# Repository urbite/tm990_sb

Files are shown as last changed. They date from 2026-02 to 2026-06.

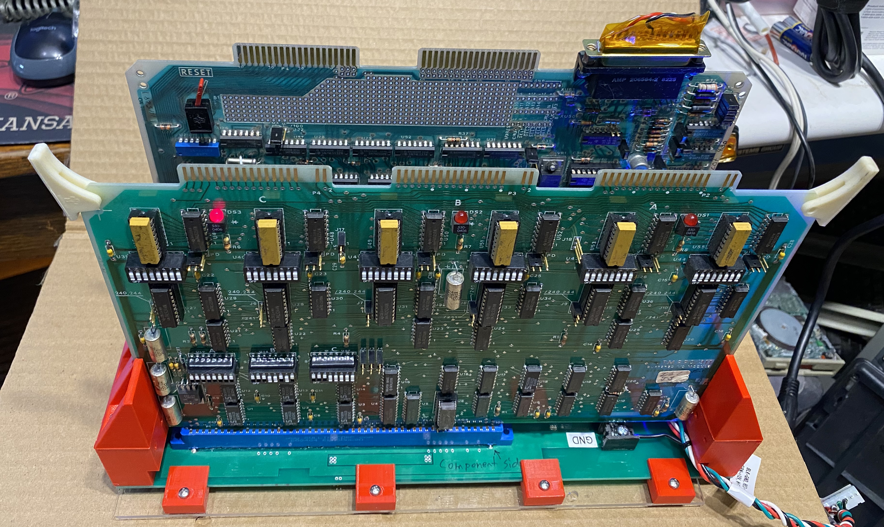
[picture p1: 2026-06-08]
mechanical/TM990_100MA+311-crop1.png

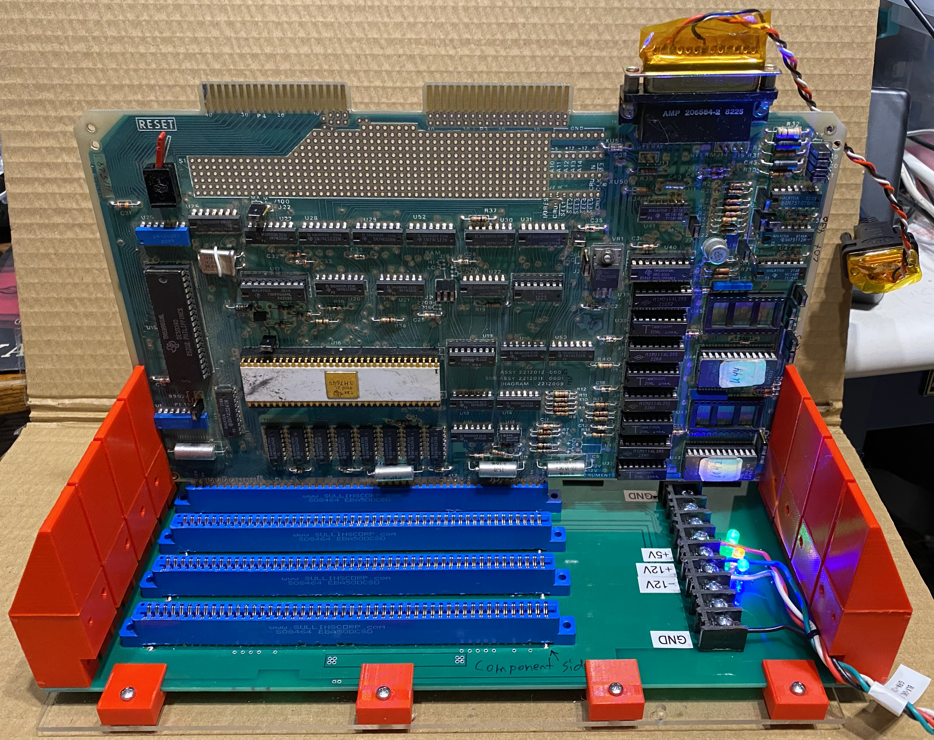
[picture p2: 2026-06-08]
mechanical/TM990_backplane+mechanicals-crop1.png

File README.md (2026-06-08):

# Scott's tm990 stuff - urbite's fork

https://www.smbaker.com/

This directory contains various projects I worked on for the TM990. In particular, it contains some boards that I designed.
Please find the article(s) on my blog for more information.

- tm990-memory. This is a memory board.

- tm990-multi. This is a multifunction board featuring memory and other features.

Note that tm990-multi-0.7 appears to be the version I fabricated and it must have had some errors
as I ended up making an 0.10 version. It's not clear to me that I ever fabricated the 0.10 version,
so please be aware that version may not have been tested.

## Urbite updates
After discovering this design and Scott's YT video demonstrating it, I contacted Scott and he provided STL files for card guide and backplane hold-down brackets that he design. These have been added in the mechanical directory, with a few photos of the printed brackets in a TM990 system with Stuart Connors backplane.

I had PCBs made using the v0.10 version, but have not finished assembly and initial bringup yet.

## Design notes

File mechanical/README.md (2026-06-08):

# TM990 Mechanicals

Thanks to Scott Baker for providing STL files for 3D-printable brackets. There are 5 different brackets needed to secure the backplane (Stuart Connor's reproduction, in this case).
1. 4-slot card guide, side 2 bottom - **tm990-case-bracket.stl**
2. 4-slot card guide, side 1 top - **tm990-case-extension.stl**
3. 4-slot card guide, side 1 bottom - **tm990-case-bracket-far.stl**
4. 4-slot card guide, side 2 top - **tm990-case-extension-far.stl**
5. Backplane hold-down brackets - **tm990-case-clip.stl**

## Assembly
### 4-slot card guide
Each 4-slot card guide consists of two pieces. These are designed to be assembled using threaded inserts that are installed using a soldering iron with a special tipe. Push the inserts into the 3D piece until the end is flush with the surface of the printed piece. Then assemble the pieces. IIRC, the holes are designe for 3mm machine screws.
Installing the threaded inserts was not a straightforward process.
- The iron should not be overly hot or the insert will be loosely fitted and difficult to get oriented correctly
- The iron needs to be perpendicular to the surface of the printed piece
- The insert needs to be pressed in the correct amount
For reliable heat insert installation, the decision was made to purchase a jig with an iron with settable temperature. The temperature is set to match the print material used. Also included were the tips for various size screw diameters, and a spring loaded stand with adjustable stop. This allows the insert to be installed perpendicular to the material, while the stop allows setting an exact depth.

For this configuration, threaded standoffs were used, with male on the upper side and female on the lower side. The assembled side 1/side 2 card guides were placed on the backplane, then the threaded standoffs were screwed into the threaded inserts by running the standoff screw through the bottom of the backplane PCB holes (that I drilled) in the backplane.

### Backplane holddown brackets
The backplane+card guide assembly is mounted on an 1/8 plexiglass sheet, using the case clips. The thicker part of the clip, between the backplane slot and edge faces downward to give the most clearance between the backplane connector pins and the plexiglass.
Holes were drilled into the plexiglass so there were roughly equally spaced and didn't interfere with the termination resistors on one side of the board. Heated threaded inserts were pressed into the plexiglass. After installing the plexiglass inserts and doing some research, I wouldn't recommend doing this. Instead I would recommend running a long screw between the top of the holddown bracket and standoff on the bottom of the plexiglass - much easier.

Here are some pics of the finished assembly.

[TM990_backplane + mechanicals](./TM990_backplane+mechanicals-crop1.png)  
[TM990_backplane + TM990/100MA + TM990/311](TM990_100MA+311-crop1.png)

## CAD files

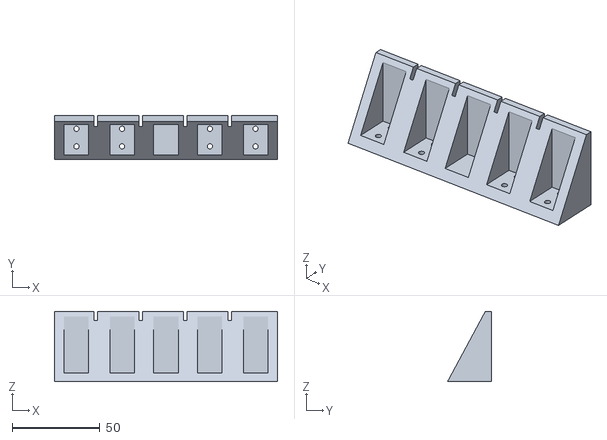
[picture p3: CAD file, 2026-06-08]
mechanical/tm990-stl-files/tm990-case-extension-far.stl
127.0 x 25.1 x 40.0

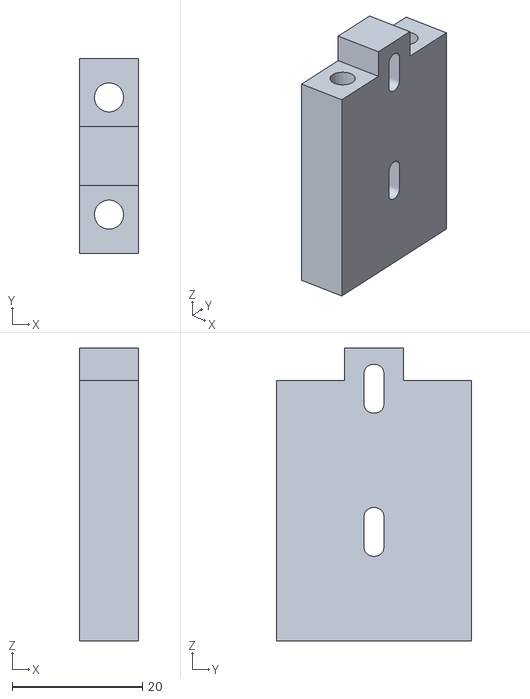
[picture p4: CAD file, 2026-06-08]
mechanical/tm990-stl-files/tm990-case-endclip-tall.stl
9.00 x 30.0 x 45.0

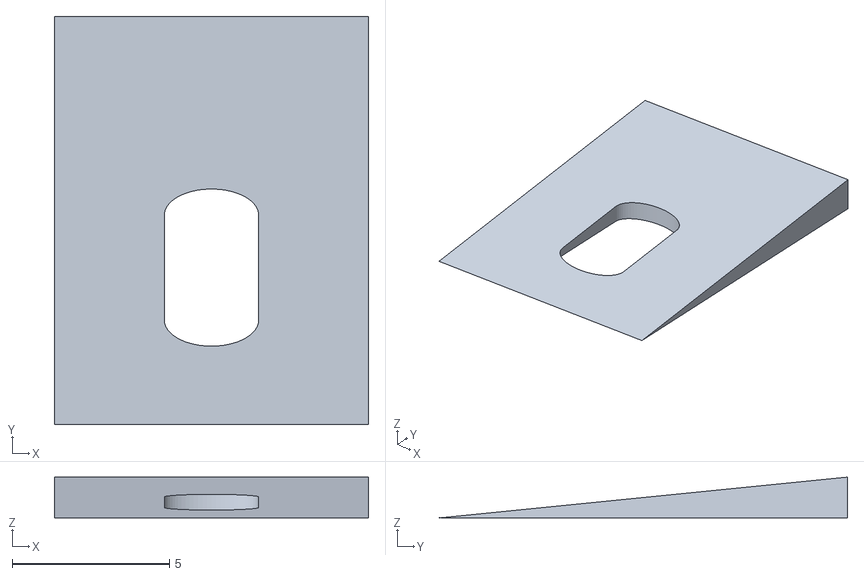
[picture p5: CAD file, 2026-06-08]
mechanical/tm990-stl-files/tm990-case-wedge.stl
10.0 x 13.0 x 1.30

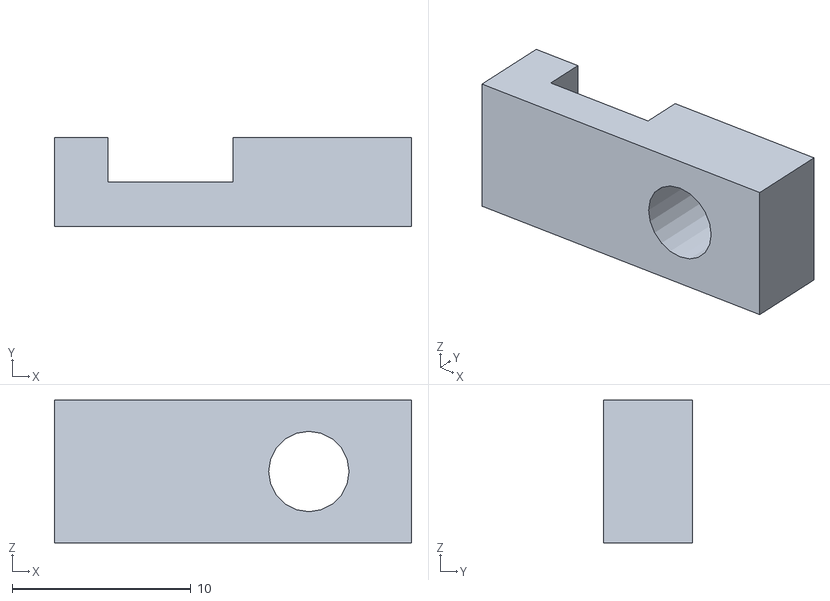
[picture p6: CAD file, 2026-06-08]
mechanical/tm990-stl-files/tm990-case-cable.stl
20.0 x 5.00 x 8.00

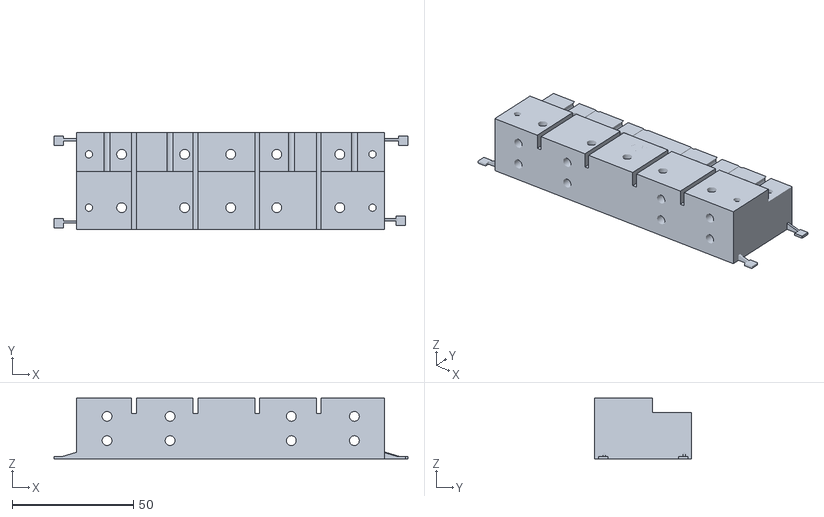
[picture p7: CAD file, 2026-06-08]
mechanical/tm990-stl-files/tm990-case-bracket-far.stl
146.0 x 40.0 x 25.1

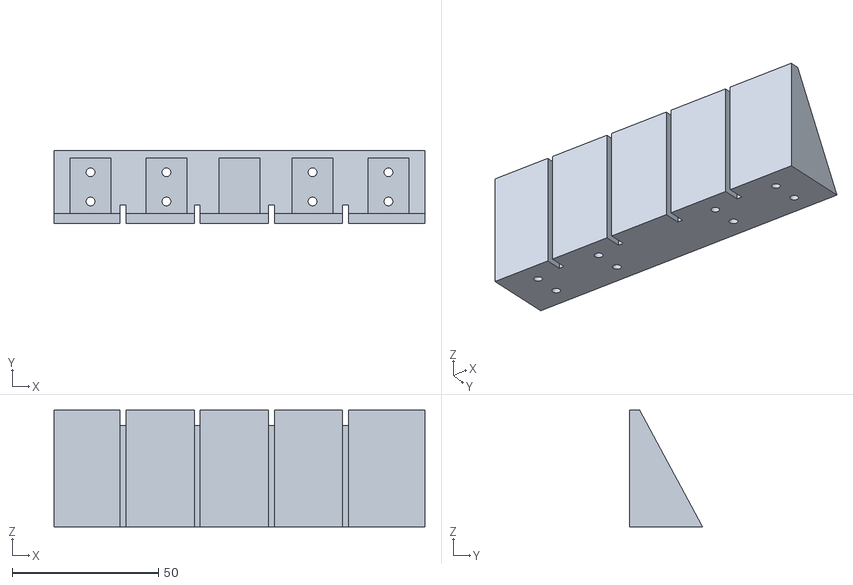
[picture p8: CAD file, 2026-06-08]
mechanical/tm990-stl-files/tm990-case-extension.stl
127.0 x 25.1 x 40.0

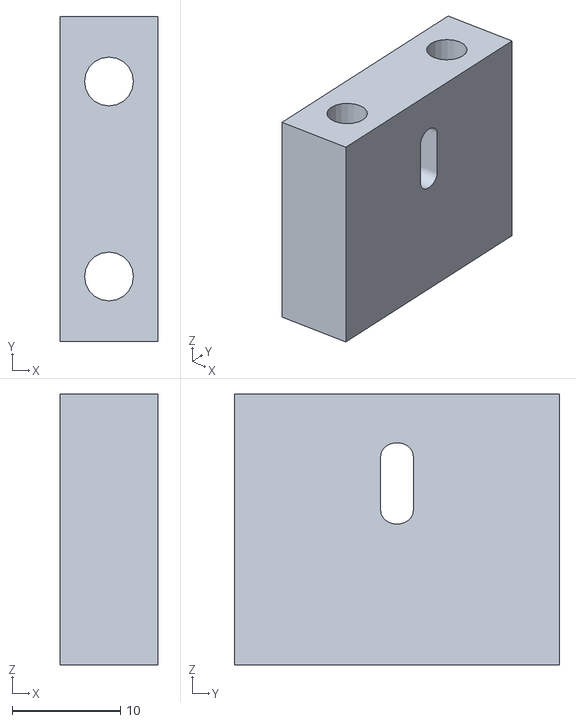
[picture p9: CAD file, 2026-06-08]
mechanical/tm990-stl-files/tm990-case-endclip-medium.stl
9.00 x 30.0 x 25.0

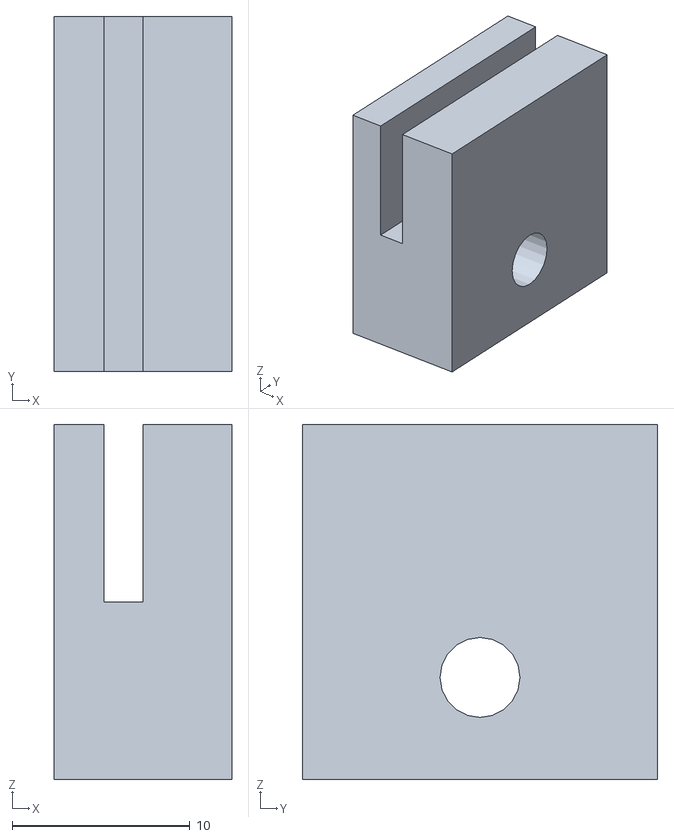
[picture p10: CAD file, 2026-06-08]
mechanical/tm990-stl-files/tm990-case-clip.stl
10.0 x 20.0 x 20.0

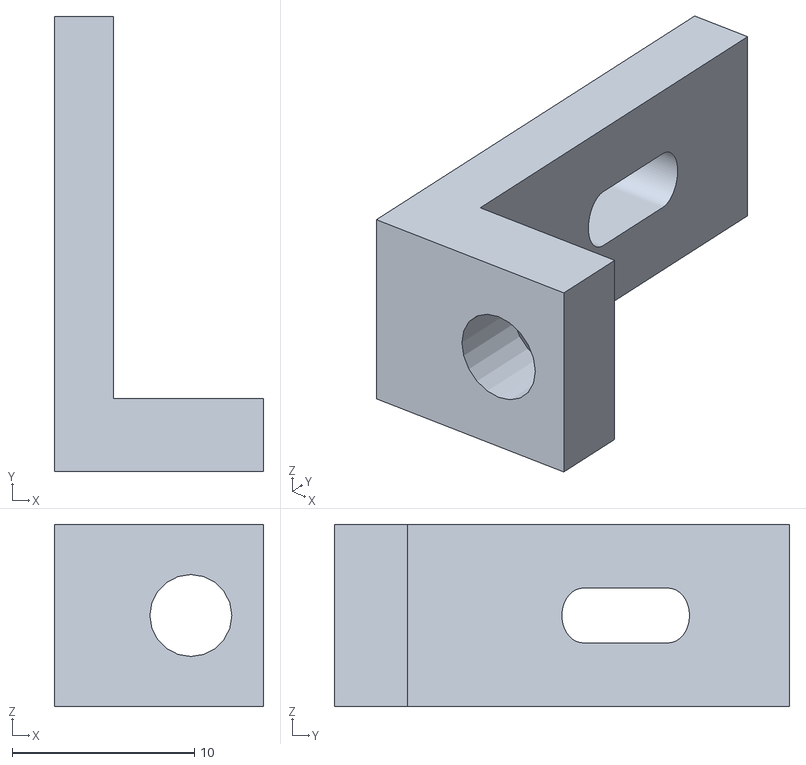
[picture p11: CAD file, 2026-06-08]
mechanical/tm990-stl-files/tm990-case-endclip.stl
11.5 x 25.0 x 10.0

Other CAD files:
mechanical/tm990-stl-files/tm990-case-bracket.stl

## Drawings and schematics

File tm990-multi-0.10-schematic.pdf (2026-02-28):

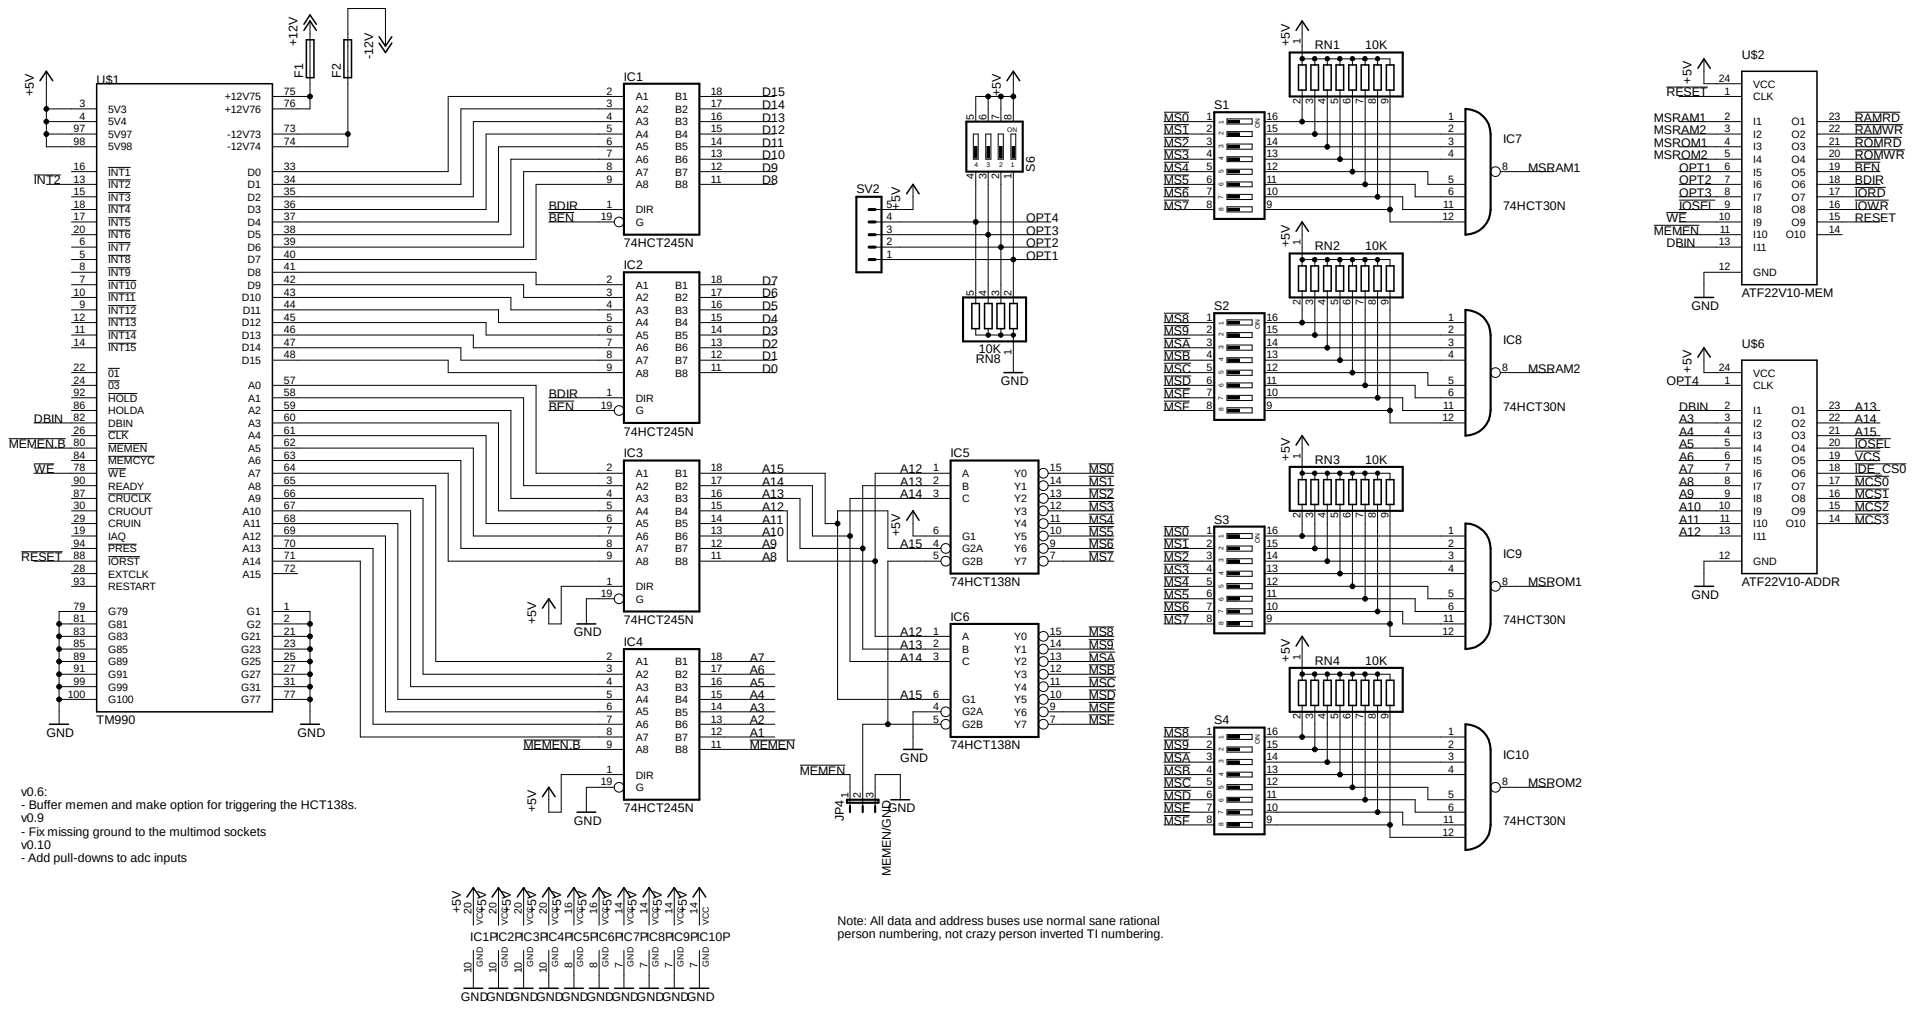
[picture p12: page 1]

15 | 2
14 | 3

- Buffer memen and make option for triggering the HCT138s.
- Fix missing ground to the multimod sockets
- Add pull-downs to adc inputs

11
10 | | 6
9 | 11

Note: All data and address buses use normal sane rational
person numbering, not crazy person inverted TI numbering.

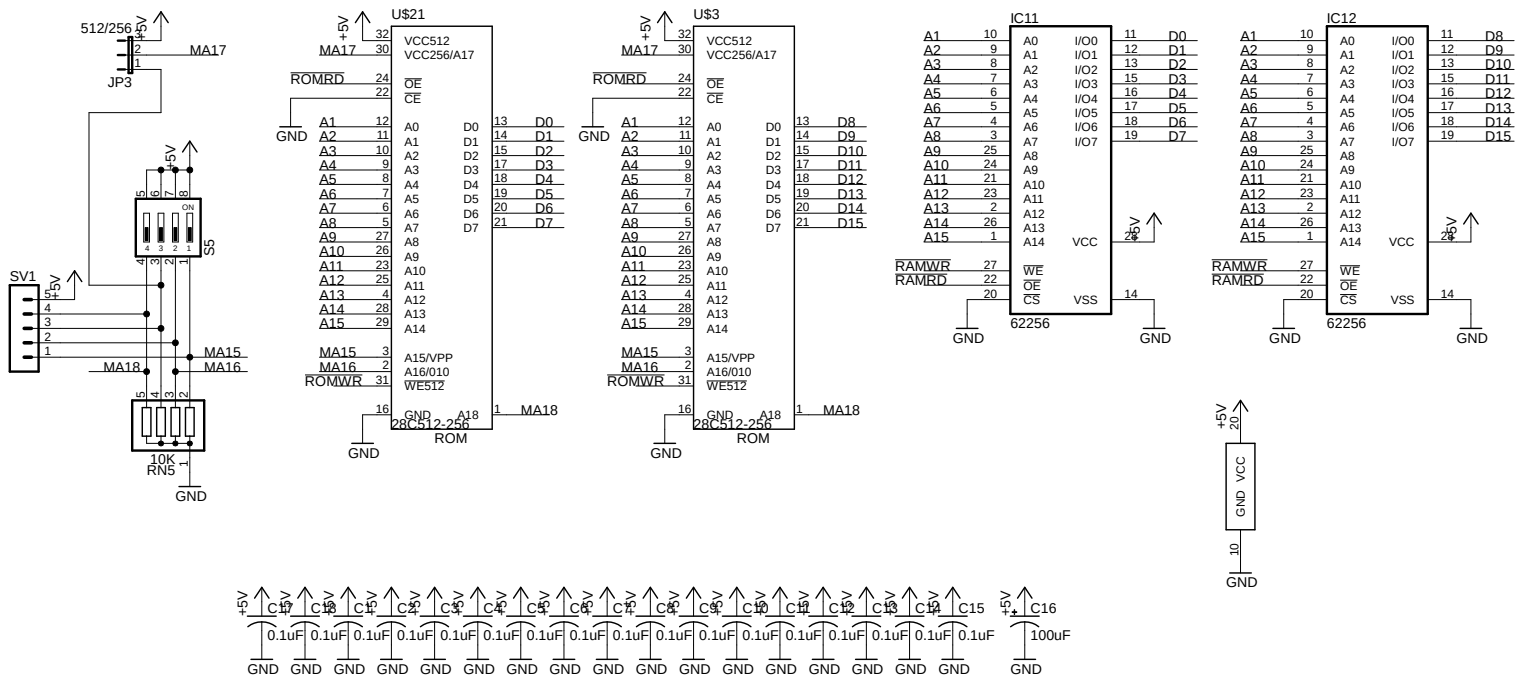
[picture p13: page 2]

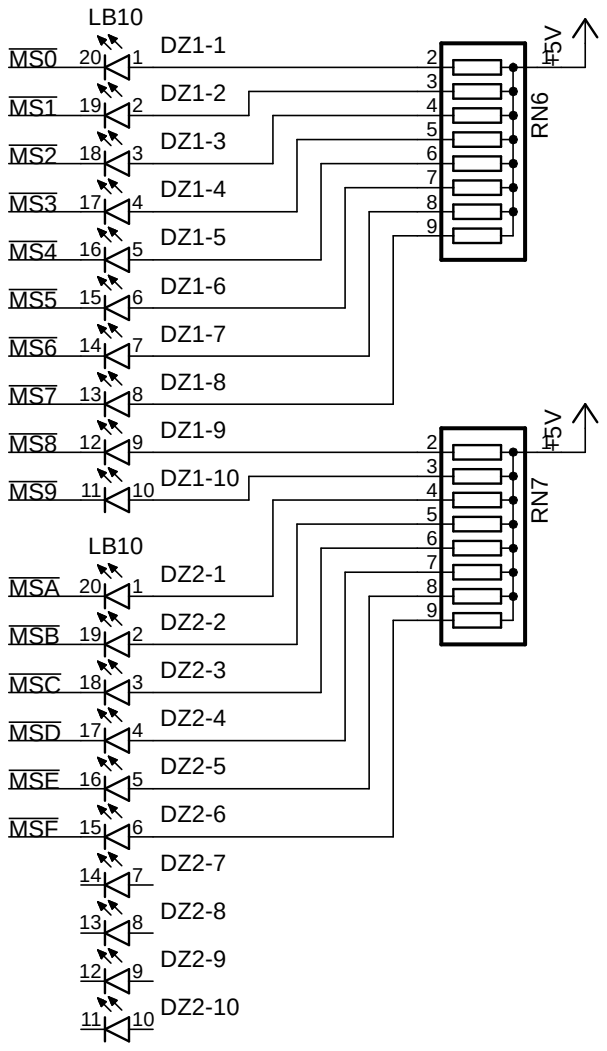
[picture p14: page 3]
MSA; MSB; MSC; MSD; MSE; MSF

9 | MA0 11 | IOWR 13 | IOR 15 | GND17 17 | MD7 19 | MD6 21 | MD5 23 | MD4 25 | MD3 27 | MD2 29 | MD1 31 | MD0 33 | GND35 35
8 NC10 | 10 MINTR1 | 12 MINTR0 | 14 NC16 | 16 +5V18 | 18 NC20 | 20 MCSO | 22 NC24 | 24 NC26 | 26 OPT1 | 28 OPT0 | 30 MDACK | 32 MDRQT | 34 +5V36 | 36

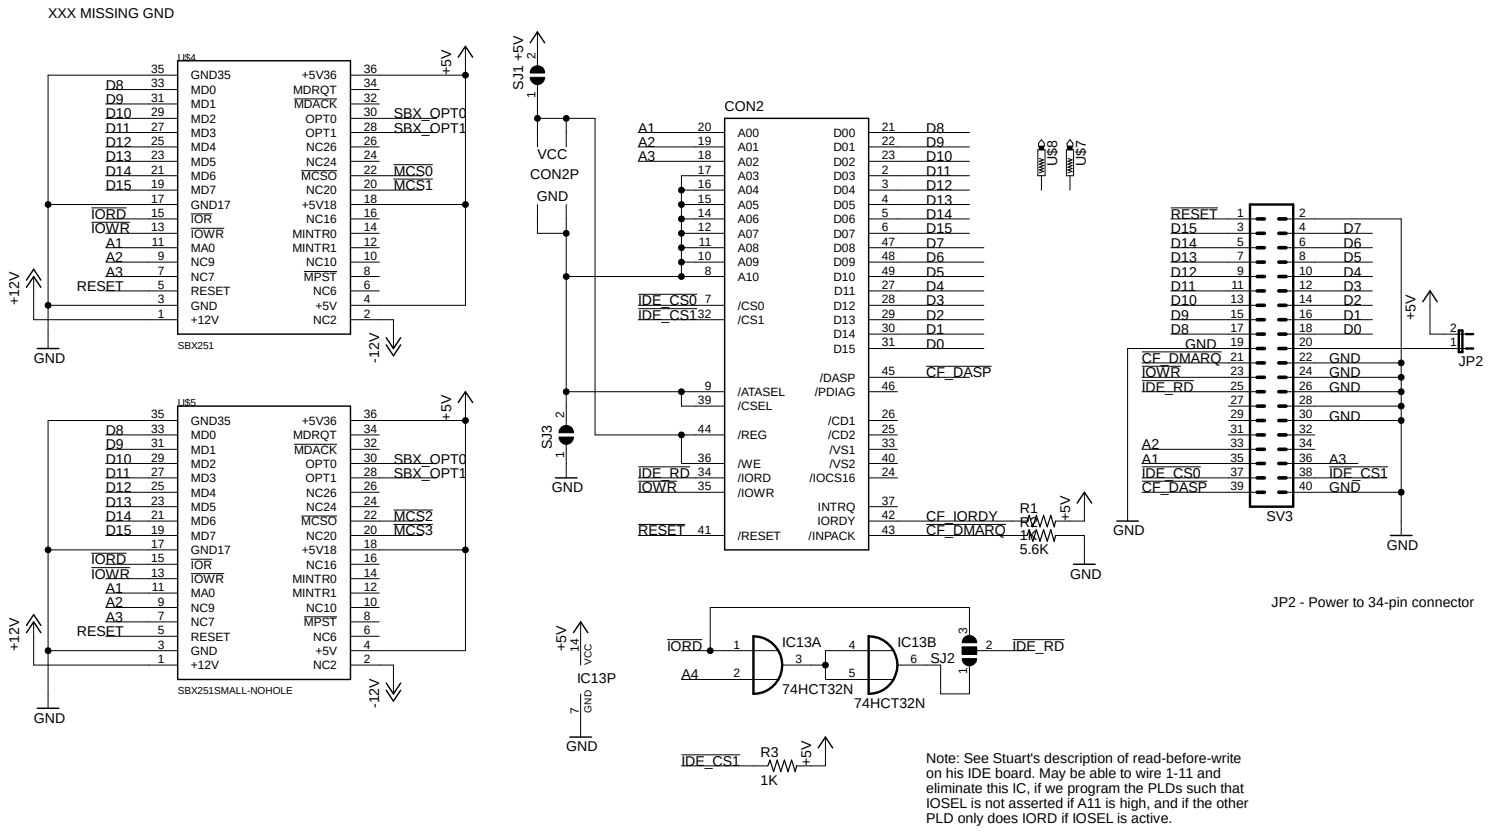
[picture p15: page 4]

A07 12 | 6
A08 11 | D0

IDE_CS0 7 IDE_CS1 9 | /CS1 32

/CSEL 39

9 D8 D9 D10 D11 D12 D13 D14 D15 | IOR 15 GND17 17 MD7 19 MD6 21 MD5 23 MD4 25 MD3 27 MD2 29 MD1 31 MD0 33 GND35 35 MA0 11 IOWR 13 | 8 NC10 10 MINTR1 12 MINTR0 14 NC16 16 +5V18 18 NC20 20 MCSO 22 NC24 24 NC26 26 OPT1 28 OPT0 30 MDACK 32 MDRQT 34 +5V36 36 SBX_OPT0 SBX_OPT1 MCS2

IORD IOWR A1 A2 A3 RESET 5 3 | | 6 MPST 4 NC6

JP2 - Power to 34-pin connector

Note: See Stuart's description of read-before-write
on his IDE board. May be able to wire 1-11 and
eliminate this IC, if we program the PLDs such that
IOSEL is not asserted if A11 is high, and if the other
PLD only does IORD if IOSEL is active.

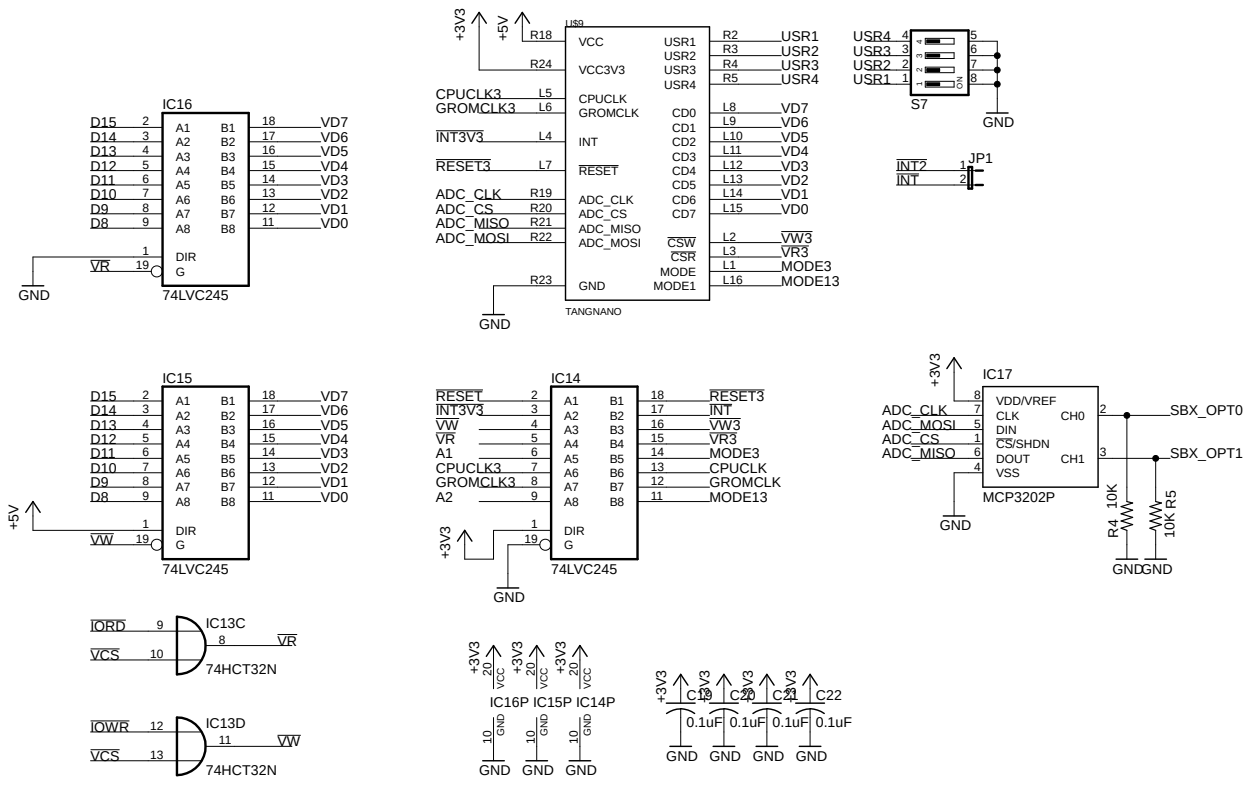
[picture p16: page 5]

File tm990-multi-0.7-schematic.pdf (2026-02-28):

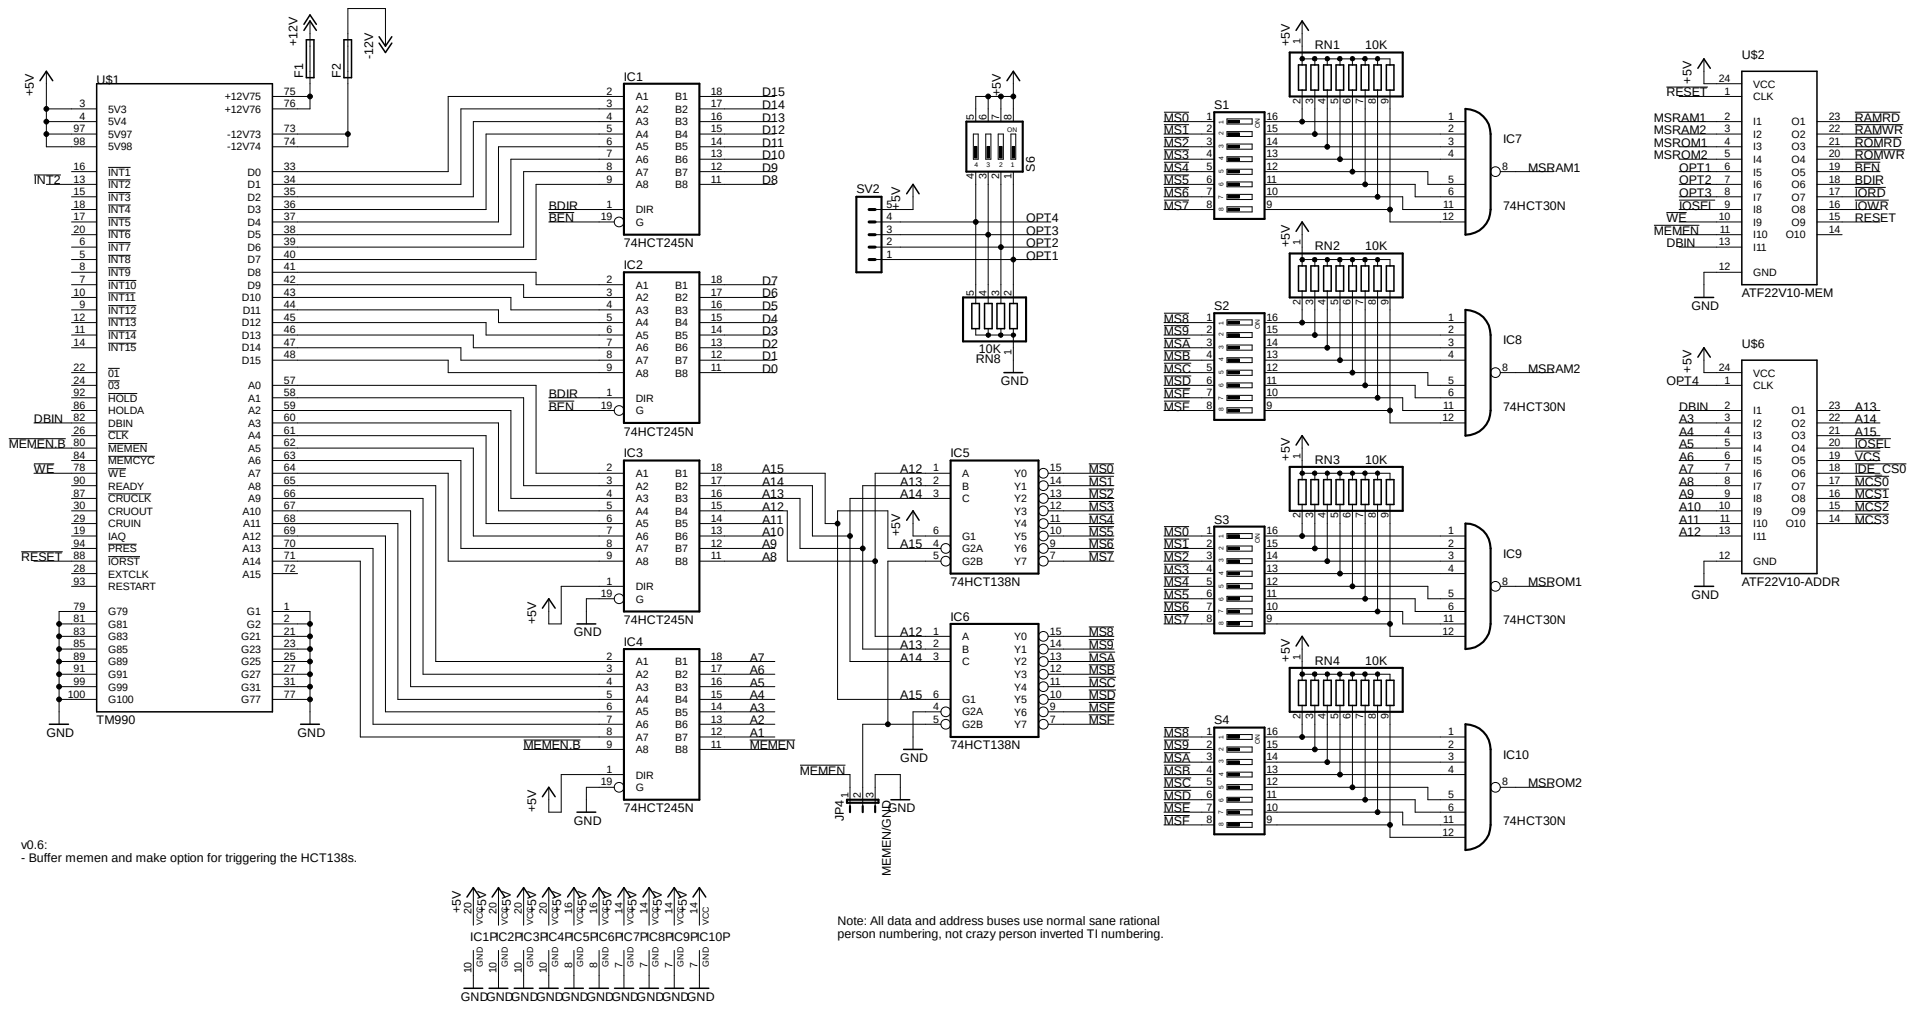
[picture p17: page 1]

15 | 2
14 | 3

11
10 | | 6
9 | 11

- Buffer memen and make option for triggering the HCT138s.

Note: All data and address buses use normal sane rational
person numbering, not crazy person inverted TI numbering.


MSA; MSB; MSC; MSD; MSE; MSF

9 | MA0 11 | IOWR 13 | IOR 15 | GND17 17 | MD7 19 | MD6 21 | MD5 23 | MD4 25 | MD3 27 | MD2 29 | MD1 31 | MD0 33 | GND35 35
8 NC10 | 10 MINTR1 | 12 MINTR0 | 14 NC16 | 16 +5V18 | 18 NC20 | 20 MCSO | 22 NC24 | 24 NC26 | 26 OPT1 | 28 OPT0 | 30 MDACK | 32 MDRQT | 34 +5V36 | 36

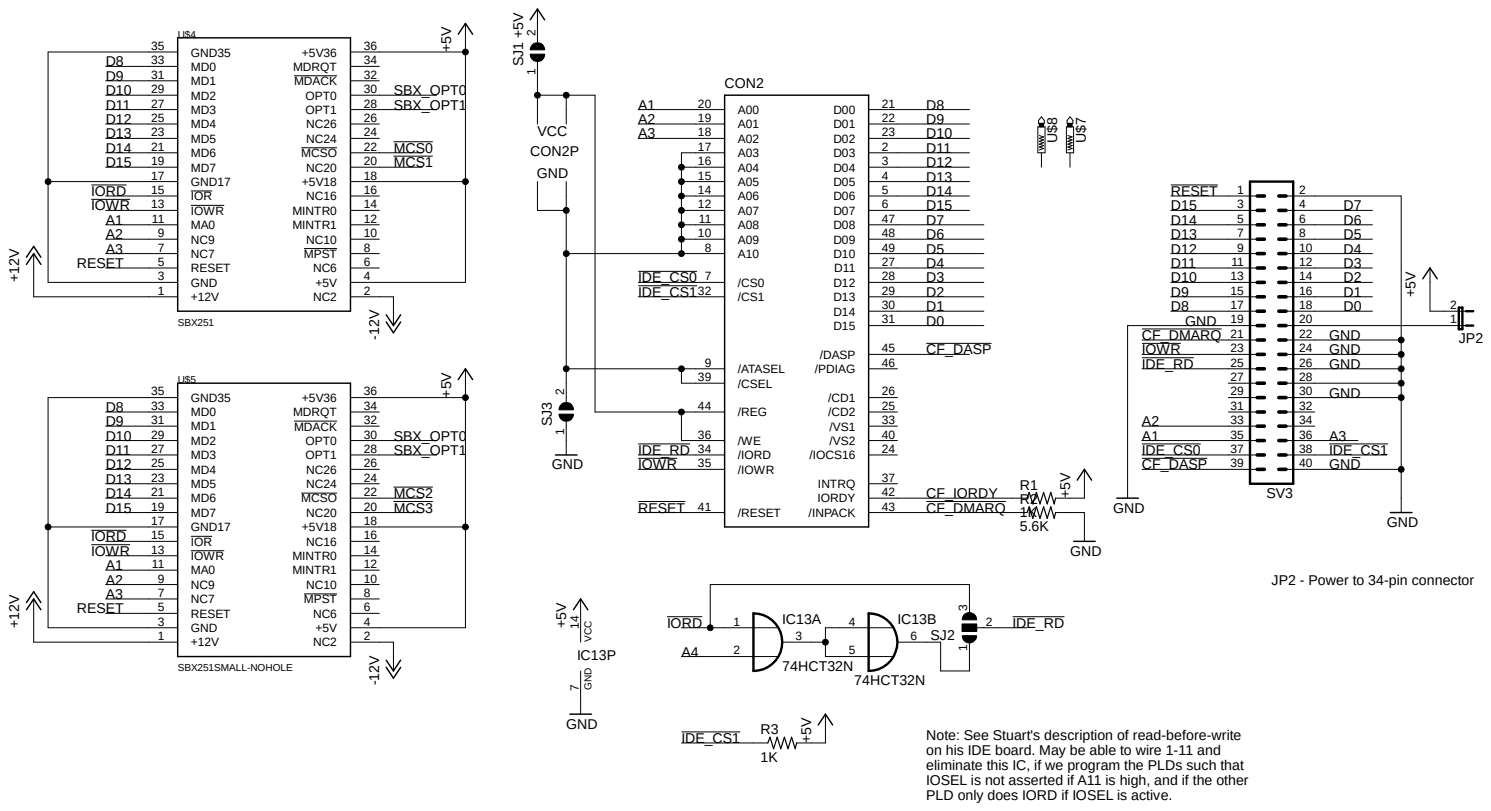
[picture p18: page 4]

A07 12 | 6
A08 11 | D0

IDE_CS0 7 IDE_CS1 9 | /CS1 32

9 D8 D9 D10 D11 D12 D13 D14 D15 | IOR 15 GND17 17 MD7 19 MD6 21 MD5 23 MD4 25 MD3 27 MD2 29 MD1 31 MD0 33 GND35 35 MA0 11 IOWR 13 | 8 NC10 10 MINTR1 12 MINTR0 14 NC16 16 +5V18 18 NC20 20 MCSO 22 NC24 24 NC26 26 OPT1 28 OPT0 30 MDACK 32 MDRQT 34 +5V36 36 SBX_OPT0 SBX_OPT1 MCS2

/CSEL 39

IORD IOWR A1 A2 A3 RESET 5 3 | | 6 MPST 4 NC6

JP2 - Power to 34-pin connector

Note: See Stuart's description of read-before-write
on his IDE board. May be able to wire 1-11 and
eliminate this IC, if we program the PLDs such that
IOSEL is not asserted if A11 is high, and if the other
PLD only does IORD if IOSEL is active.

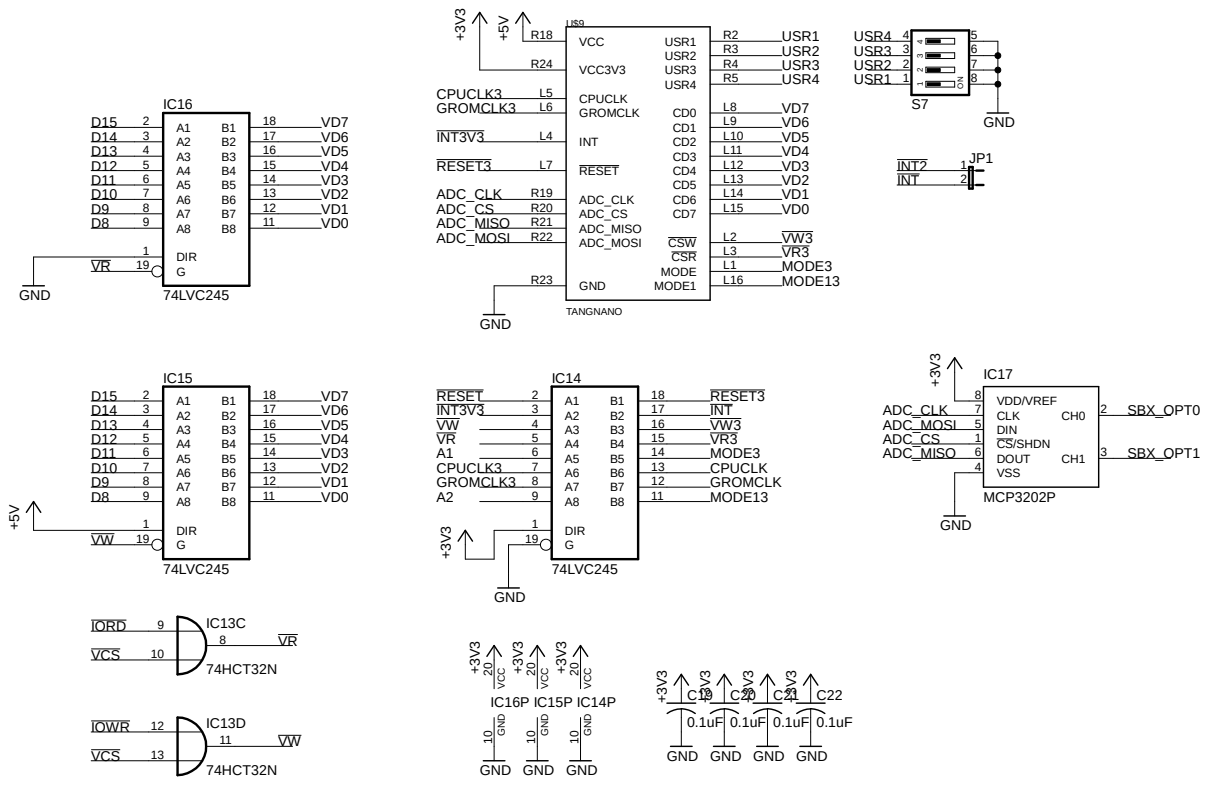
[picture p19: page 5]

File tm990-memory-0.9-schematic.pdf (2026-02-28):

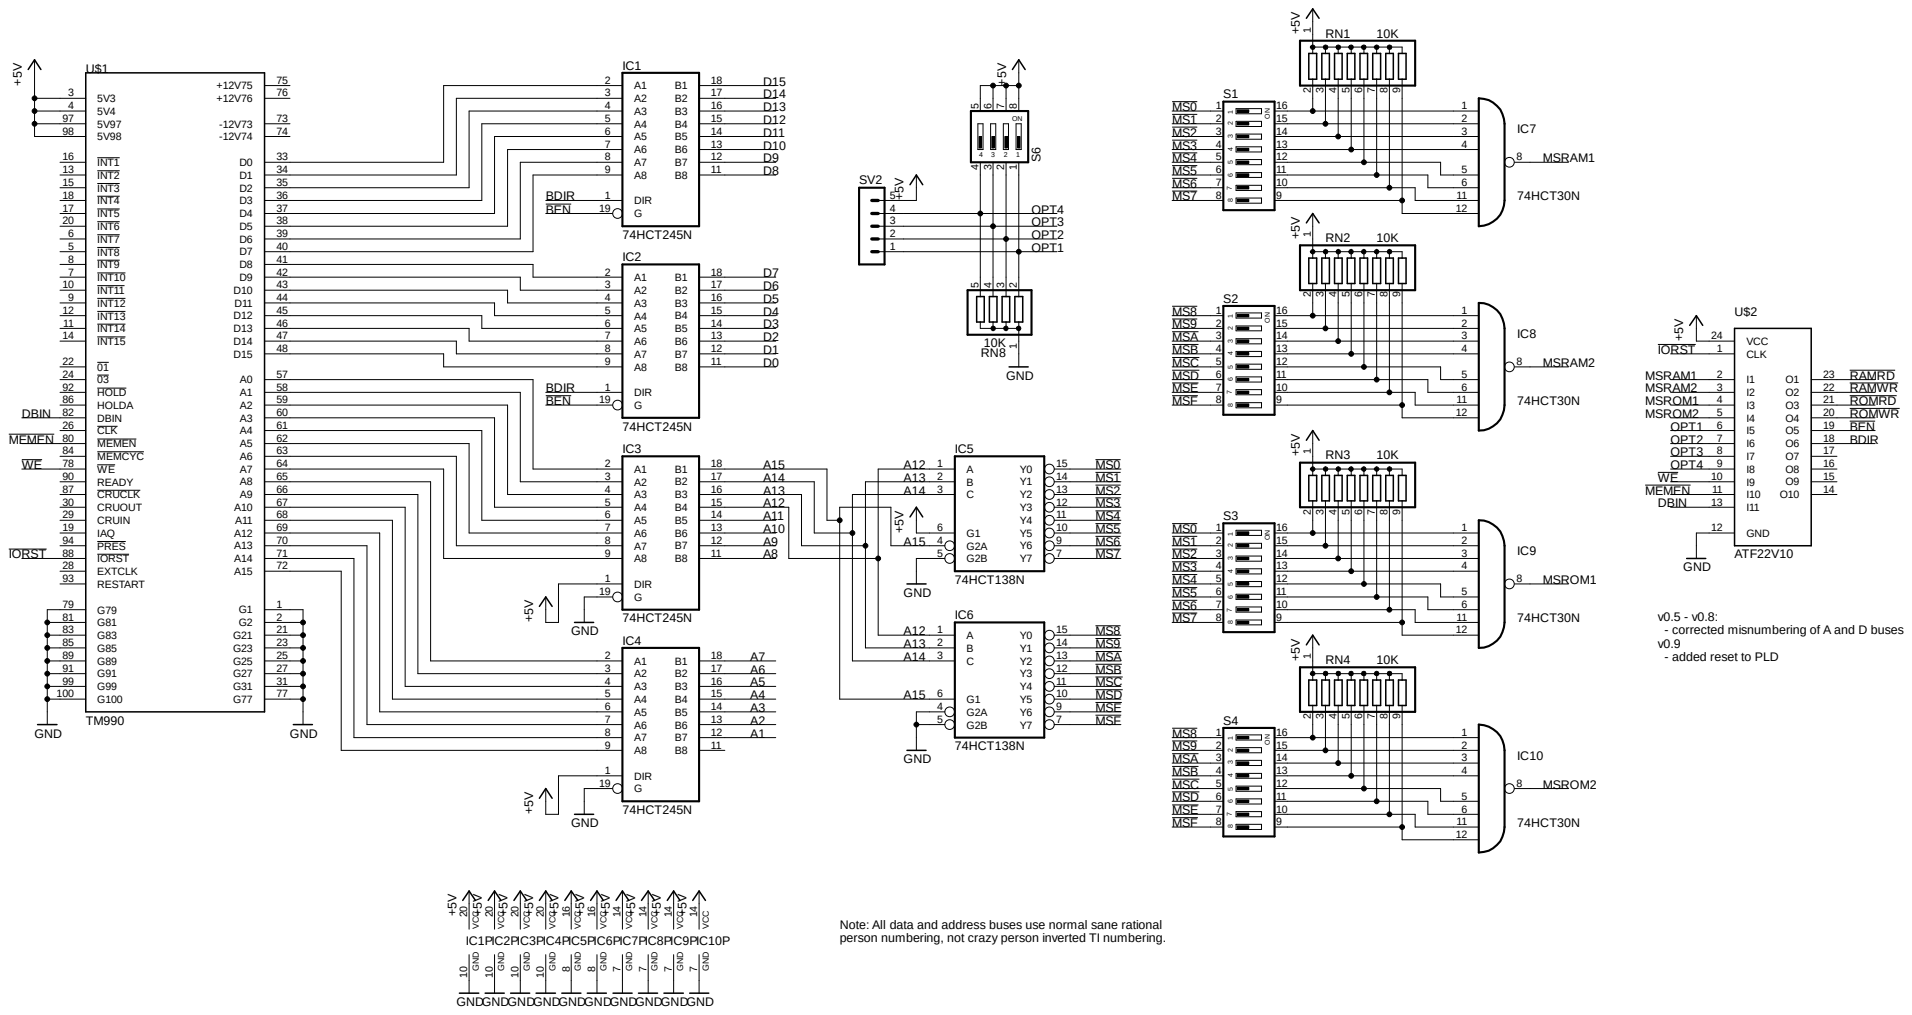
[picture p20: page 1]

12
11
10 | 6

- corrected misnumbering of A and D buses
- added reset to PLD

15 | 2
14 | 3
13 | 4

10 | | 6
9 | 11

Note: All data and address buses use normal sane rational
person numbering, not crazy person inverted TI numbering.

512/256

## VCC512 32

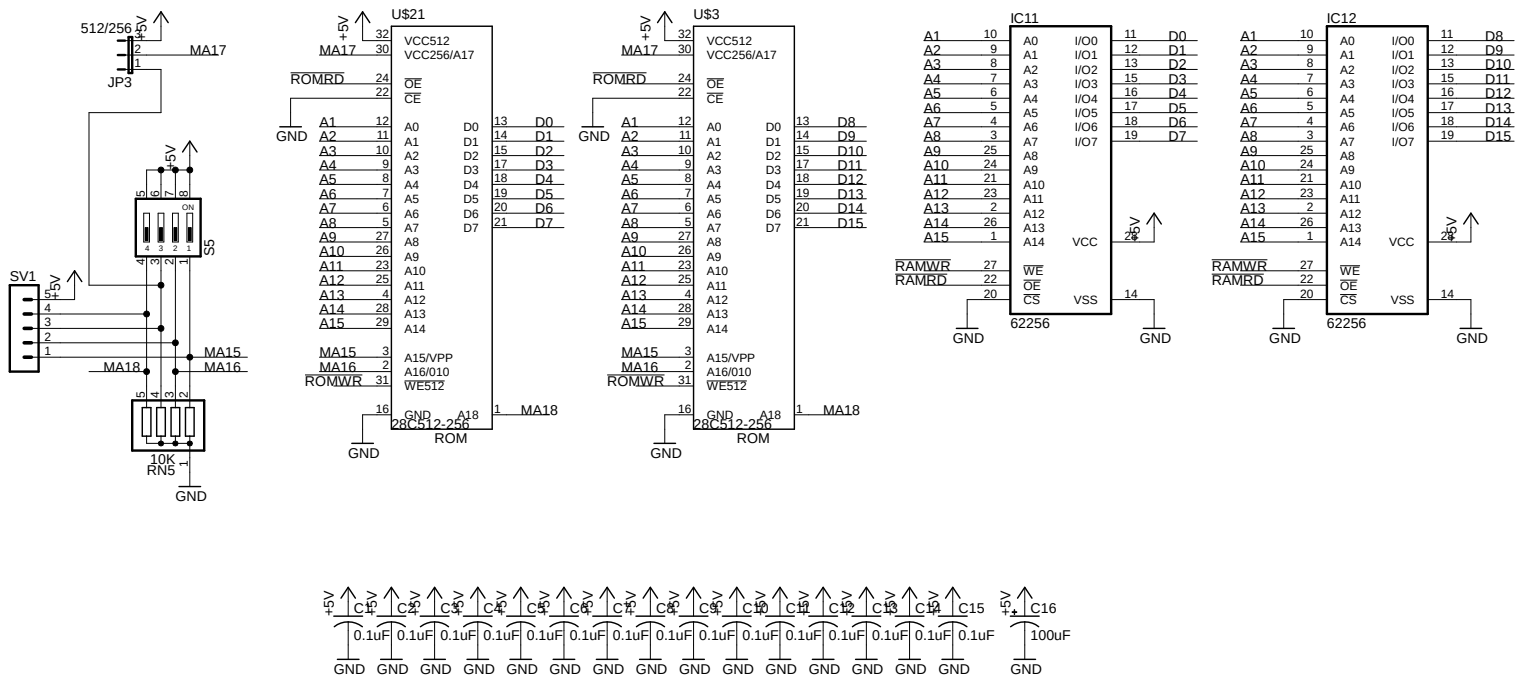
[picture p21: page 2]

LB10

MSA; MSB; MSC; MSD; MSE; MSF

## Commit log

2026-02-28 check in gerbers and schematics
    [tm990-memory.GBL, tm990-memory.GBO, tm990-memory.GBS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]
2026-06-08 Add card guide and backplane bracket STL files
    - STL files provided by Scott Baker
    - add card guide assembly notes
    - add pics of assembed example system using 3D-printed brackets
    - add iSBX MultiModule reference docs
    [tm990-case-bracket-far.stl, tm990-case-bracket.stl, tm990-case-cable.stl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]
